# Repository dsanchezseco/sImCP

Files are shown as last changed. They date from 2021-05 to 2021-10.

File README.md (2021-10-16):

# **sImCP**

or *simple ICP* for the friends

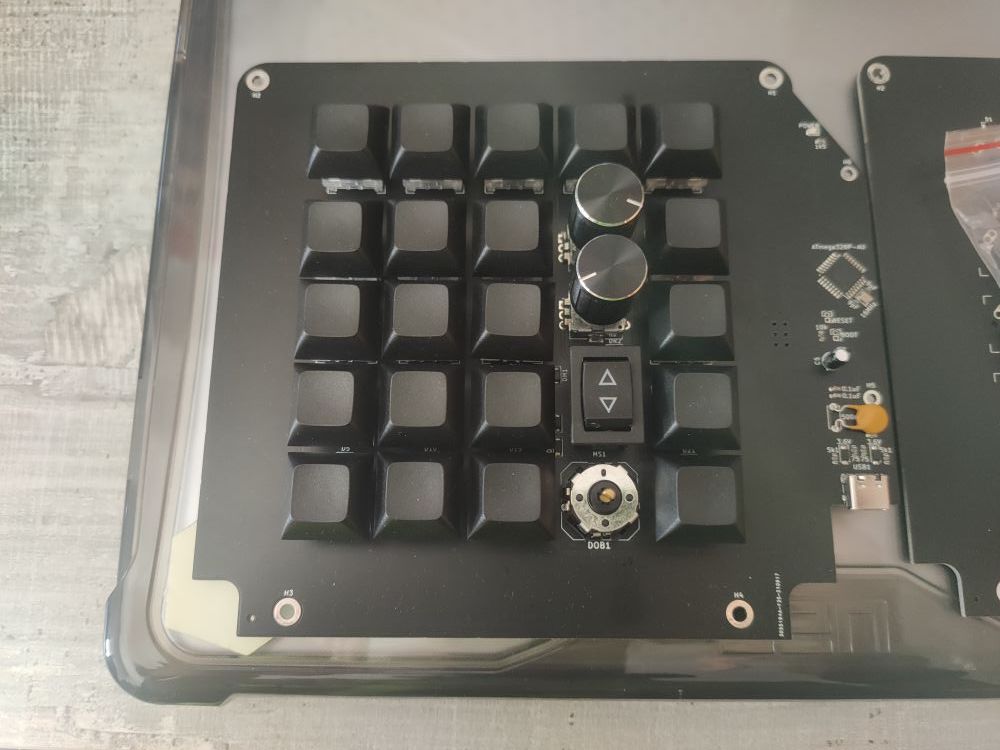
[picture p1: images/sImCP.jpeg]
simcp


sImCP is **custom PCB** powered by an atmega328p to emulate the different aircraft up front controlers (UFC) and input control panels (ICP), mainly a mix of the F-18 and the F-16 panels but with support for others like the AV-8B or the A-10C, for flight simming in DCS an other simulators.

The origin of the project was to have something in the empty space of the MFD in my cockpit, and as such the holes align with the holes and mounting of the Thrustmaster MFDs

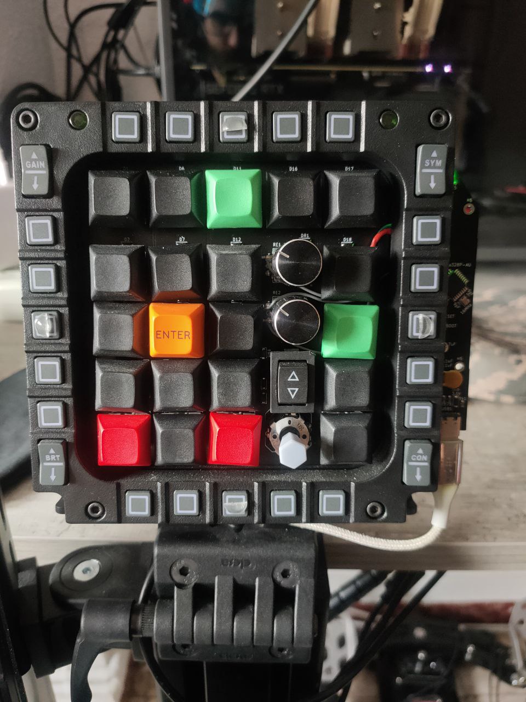
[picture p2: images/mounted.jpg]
mounted


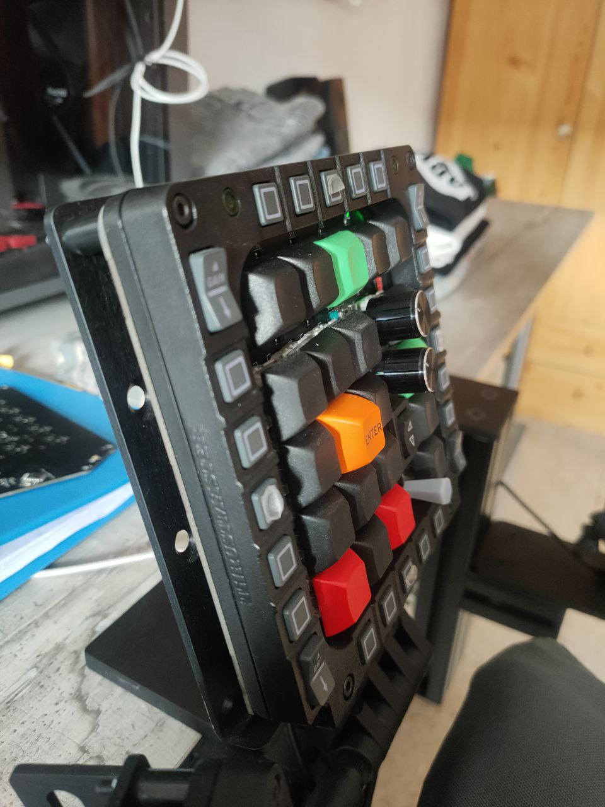
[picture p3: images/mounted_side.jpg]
mounted side


The features that define the **sImCP** are:

* Atmega328p
* USB-C
* 21 keys (MX or ALPS mechanical switches)
* 2 encoders with push
* 1 2-Way switch
* 1 4-Way with push and encoder (called dobber)
* [QMK](https://qmk.fm) support
* Thrustmaster Cougar MFD mountable

In fact it is a **fully programmable keyboard** and as such its keys behaviour can be changed by creating a new custom keymap with QMK and flashing it to the board

### It is a keyboard, so use the keyboard column on DCS to do the keybinds

### **Default keymap**

The default keymap has the following keycodes:

```

   ------------ ----------- ------------- ------------- ------------
   |  LCTL+A  | |  LCTL+O  | |  LCTL+U  | |  LCTL+I   | |  LCTL+D  |
   ------------ ------------ ------------ ------------- ------------
   ------------ ------------ ------------ ------------- ------------
   |  RCTL+1  | |  RCTL+2  | |  RCTL+3  | | ENCODER 1 | |  LCTL+H  |
   ------------ ------------ ------------ ------------- ------------
   ------------ ------------ ------------ ------------- ------------
   |  RCTL+4  | |  RCTL+5  | |  RCTL+6  | | ENCODER 2 | |  LCTL+T  | 
   ------------ ------------ ------------ ------------- ------------
   ------------ ------------ ------------ ------------- ------------
   |  RCTL+7  | |  RCTL+8  | |  RCTL+9  | |  2-WAY    | |  LCTL+N  |
   ------------ ------------ ------------ ------------- ------------
   ------------ ------------ ------------ ------------- ------------
   |  RCTL+]  | |  LCTL+0  | |  RCTL+[  | |  DOBBER   | |  LCTL+;  |
   ------------ ------------ ------------ ------------- ------------

#########################################
   ENCODER 1
#########################################
  RCTL+F   LCTL+Q    RCTL+C
   (         |         )
   v         v         v

#########################################
   ENCODER 2
#########################################
  RCTL+Y   LCTL+J    RCTL+G
   (         |         )
   v         v         v

#########################################
   2-WAY
#########################################
  LCTL+K
    ^
    |

    |
    v
  LCTL+X

#########################################
   DOBBER
#########################################
          LCTL+M                     
            ^                        
            |                       RCTL+B   RCTL+W    RCTL+Z 
LCTL+P <-       -> LCTL+R            (         |         )
            |                        v         v         v
            v
          LCTL+W
```

### **Gamepad**

Instead of being recognised as a keyboard the sImCP can be flashed with a custom made firmware to act as a gamepad and output a button instead a keycode on each of the keys. 

**This feature is currently WIP**

### **Flashing** 

To flash a new keymap refeer to the [FIRMWARE README.md](READY%20TO%20USE%20FILES/FIRMWARE/README.md) under the `READY TO USE FILES` folder. The default keymap file is provided as well in the same folder.

### READY TO USE inventory

* PCB_FABRICATION: what's needed to order more to JLCPCB already in the correct format
* PCB_3DMODEL: in case you want to print something :)
* FIRMWARE: the code to make it running ready to flash
* 3D_PRINTABLES: stuff ready to print like the **dobber cap (by Joghurt - thanks!)**

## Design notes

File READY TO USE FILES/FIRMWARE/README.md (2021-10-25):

These files are the firmware for the sImCP keyboard.

* QMK : regular [QMK](https://github.com/qmk/qmk_firmware) firmware to act as a keyboard. It uses *modifier/s+key* for each of the actions. Can have collisions with default game keybinds but it is recognized in every game/sim that uses a keyboard.

# Flashing - CAUTION!!!

This is a delicate operation. Please follow all the steps and in case of doubt do not procced, **ASK FOR HELP**
## Preparation

1. Grab a piece of wire, tweezers or something conductive to be able to short the `boot` jumper 
2. Download and install [QMK Toolbox](https://github.com/qmk/qmk_toolbox/releases) (can be used with any of the versions)
3. Download the desired `FIRMWARE` from this same folder

## Flashing

1. unplug the board
2. open QMK toolbox
3. click on open and select the downloaded .hex file

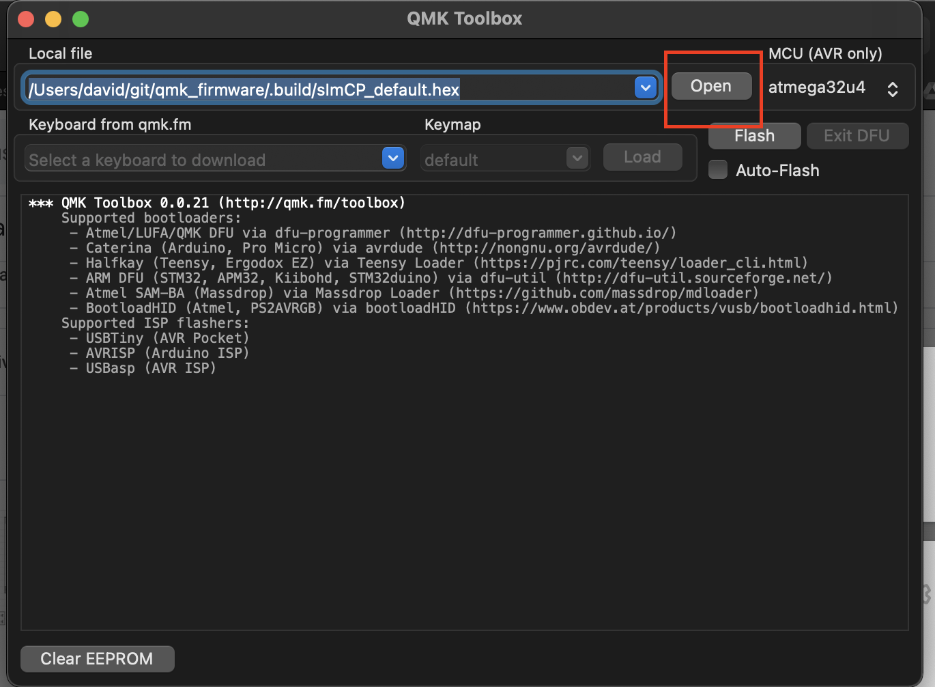
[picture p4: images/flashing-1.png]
select the hex file

￼
4. under MCU select atmega328p

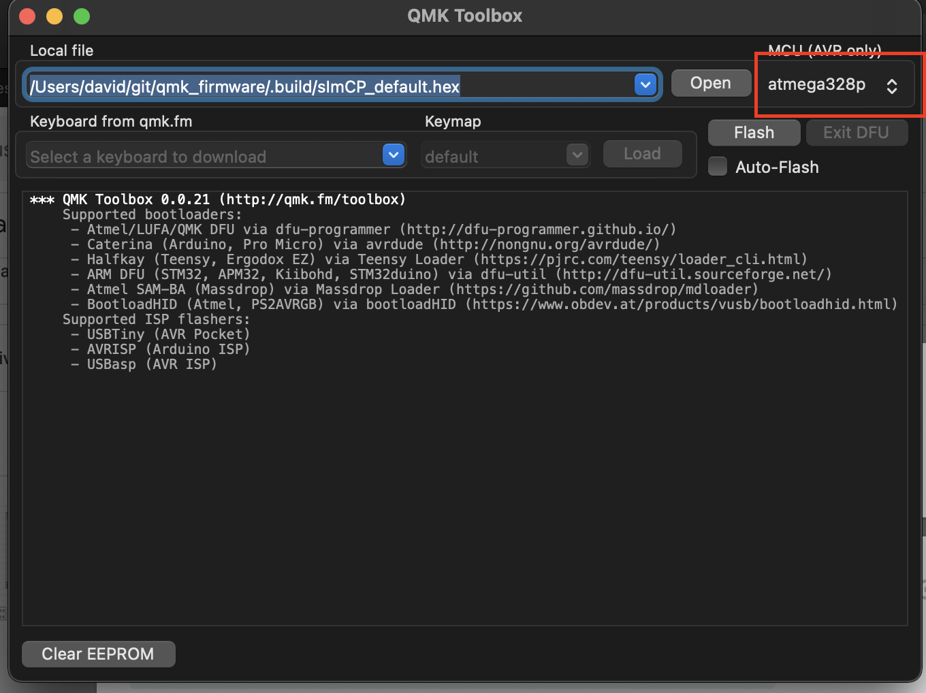
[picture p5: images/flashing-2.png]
select the MCU


5. bridge the BOOT pins with a piece of wire or tweezers

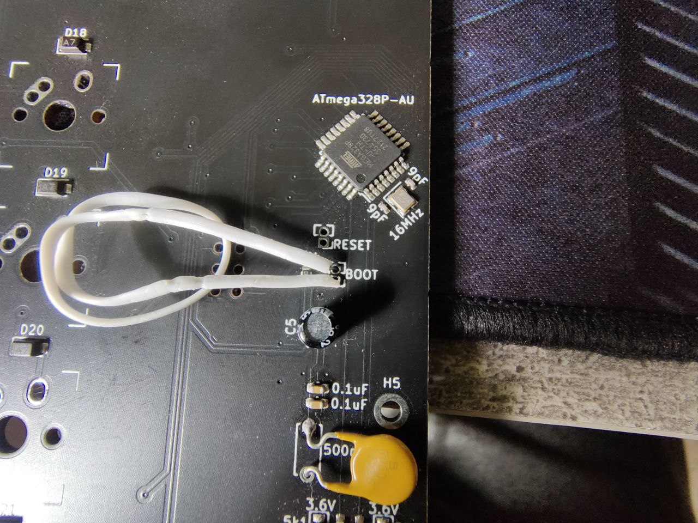
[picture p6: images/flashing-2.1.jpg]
bridge boot


1. Connect the board. The green power light should be off and on the toolbox you should see the yellow line (you can keep the bridge in, if the light goes on, try again, the light has to stay off)
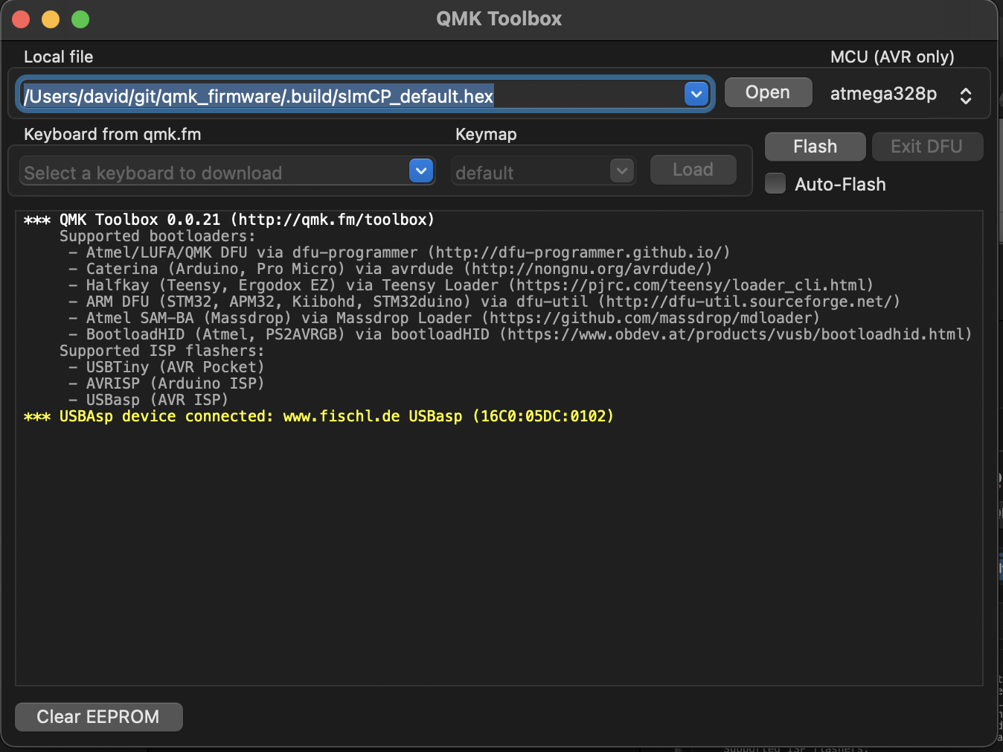
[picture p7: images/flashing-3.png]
MCU recognized


￼

### VERIFY YOU HAVE atmega328p SELECTED!

7. Click on Flash to start the process DO NOT UNPLUG THE BOARD OR CLOSE THE TOOLBOX!

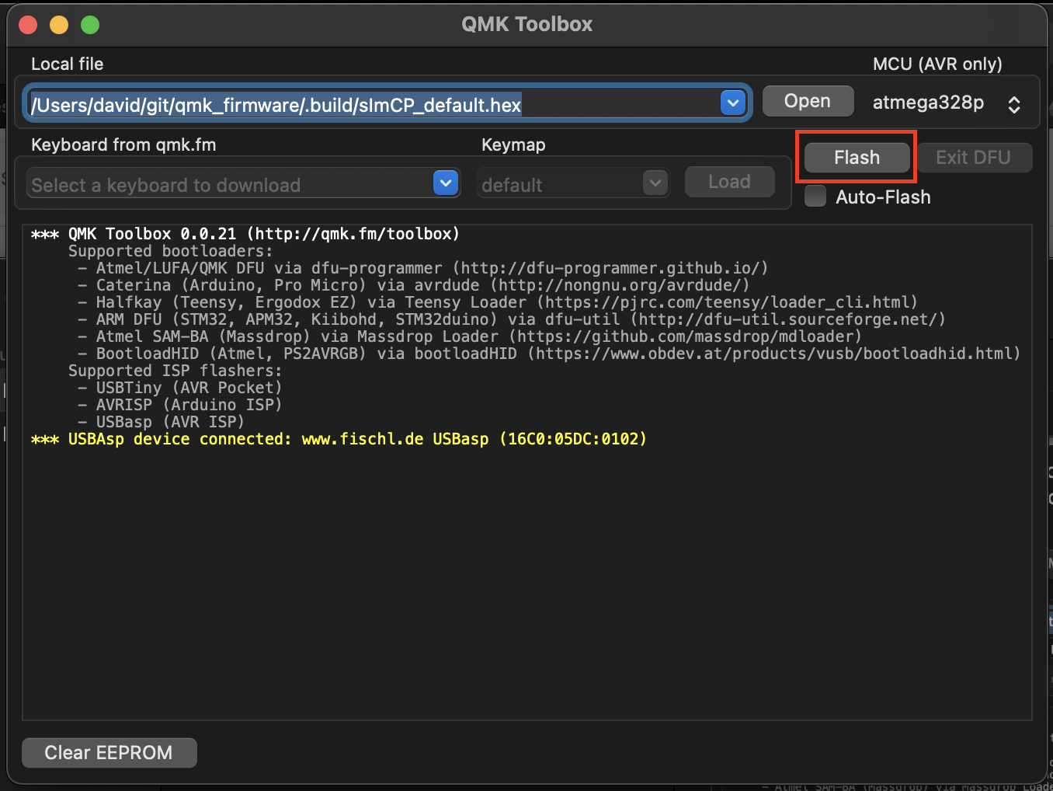
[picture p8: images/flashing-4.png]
flash

￼

When the process is finished you should see
￼
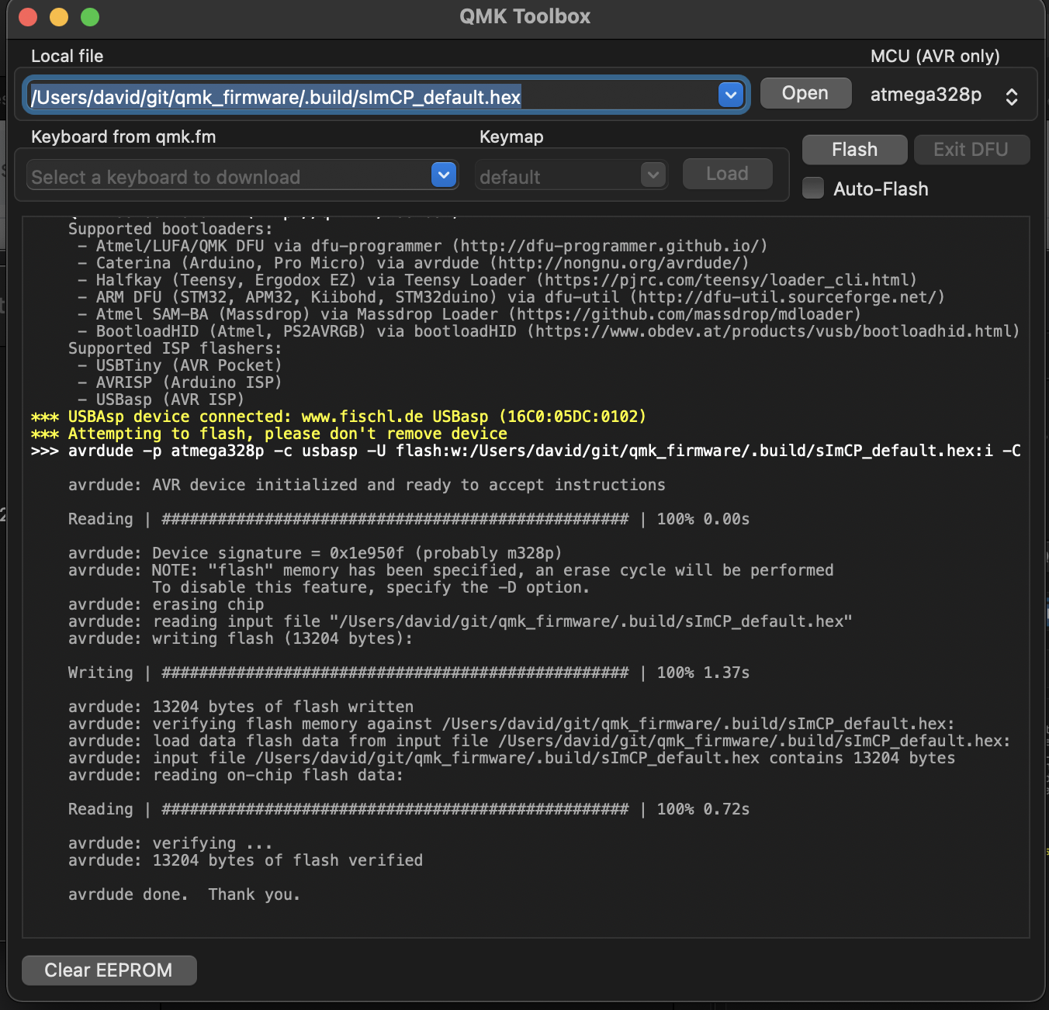
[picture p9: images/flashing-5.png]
done


8. Reconnect the board  or briefly bridge the RESET pins and you are done

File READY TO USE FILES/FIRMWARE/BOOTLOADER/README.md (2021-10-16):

# WARNING!!! You probably don't need these files

This files are to be used with and ISP flasher NOT with regular USB programming.

**If you do not know the terms MCU, ISP, BOOTLOADER or V-USB this is probably not for you.** You have been warned.

## You do not need these files unless the MCU is blank or you sourced the PCBs yourself

The files here are ready to flash a new MCU with both the **bootloader** and the **firmware**. There are two variants:

* QMK : regular [QMK](https://github.com/qmk/qmk_firmware) firmware to act as a keyboard. It uses *modifier/s+key* for each of the actions. Can have collisions with default game keybinds but it is recognized in every game/sim that uses a keyboard.
* Gamepad : custom firmware to act as a gamepad. It is recognized as an standalone device which uses buttons for each action. Do not have collisions with default keybinds but some games/sims may not recognized.

Both versions use (a modified version of ) [USBaspLoader](https://github.com/dsanchezseco/USBaspLoader) to be used with this specific PCB, do not use it with any other.

USBaspLoader provides V-USB (virtual USB) capabilities for not USB ready devices like the **atmega328p** being used here. This way the PCB can use a **low speed USB** controlled via software and **firmware flashing through USB**.

# Flashing - CAUTION!!!

TODO

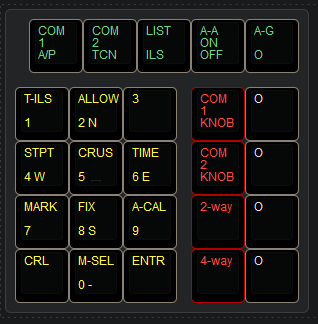
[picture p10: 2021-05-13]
images/sketch.png

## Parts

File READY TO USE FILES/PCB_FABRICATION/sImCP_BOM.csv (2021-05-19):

Comment | Designator | Footprint | LCSC
9pF | C1,C2 | Capacitor_SMD:C_0402_1005Metric | C111805
0.1uF | C3,C4 | Capacitor_SMD:C_0603_1608Metric | C14663
4.7uF | C5 | Capacitor_SMD:CP_Elec_4x5.3 | C134741
D_Small | D1,DR1,DM1,DB1,D2,DR2,DM2,D3,D4,D5,D6,D7,D8,D9,D10,D11,D12,D13,D14,D15,D16,D17,D18,D19,D20,D21 | SOD-123FL:D_SOD-123FL | C426570
RKJXT1F42001 | DOB1 | ALPS_RKJXT1F42001:RKJXT1F42001 | C160841
3.6V | DZ1,DZ2 | Diode_SMD:D_SOD-123 | C82565
500mA | F1 | Capacitor_THT:C_Disc_D5.0mm_W2.5mm_P5.00mm | C208476
MountingHole | H1,H2,H3,H4 | MountingHole:MountingHole_3.2mm_M3_ISO7380_Pad
MountingHole | H5,H6 | MountingHole:MountingHole_2.2mm_M2_DIN965_Pad
AVR-ISP-6 | J1 | random-keyboard-parts:Reset_Pretty-Mask
POWER | LED1 | LED_SMD:LED_0805_2012Metric | C205442
Momentary Rocker Switch | MS1 | RockerSwitch:RockerSwitch
MX-NoLED | MX1,MX2,MX3,MX4,MX5,MX6,MX7,MX8,MX9,MX10,MX11,MX12,MX13,MX14,MX15,MX16,MX17,MX18,MX19,MX20,MX21 | MX_Alps_Hybrid:MX-1U-NoLED | C400228
5k1 | R1,R2 | Resistor_SMD:R_0603_1608Metric | C23186
75 | R3,R4 | Resistor_SMD:R_0603_1608Metric | C4275
1k5 | R5,R7 | Resistor_SMD:R_0603_1608Metric | C22843
10k | R6 | Resistor_SMD:R_0603_1608Metric | C25804
Rotary_Encoder_Switch | RE1,RE2 | Rotary_Encoder:RotaryEncoder_Alps_EC11E-Switch_Vertical_H20mm | C255515
RESET | SW1 | Connector_PinHeader_1.27mm:PinHeader_1x02_P1.27mm_Vertical
BOOT | SW2 | Connector_PinHeader_1.27mm:PinHeader_1x02_P1.27mm_Vertical
ATmega328P-AU | U1 | Package_QFP:TQFP-32_7x7mm_P0.8mm | C14877
USB_C_Receptacle_USB2.0 | USB1 | Connector_USB:USB_C_Receptacle_XKB_U262-16XN-4BVC11 | C393939
16MHz | Y1 | Crystal:Crystal_SMD_2520-4Pin_2.5x2.0mm | C280090

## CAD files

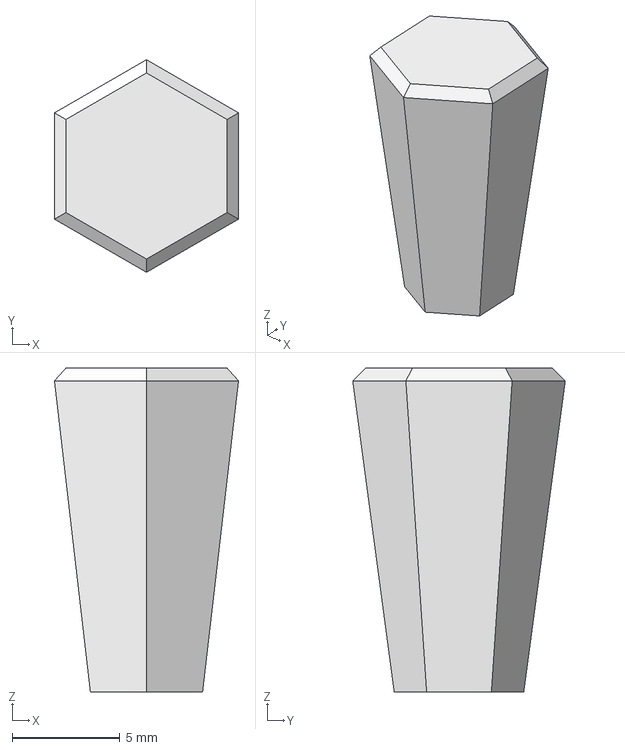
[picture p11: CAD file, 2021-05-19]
READY TO USE FILES/3D_PRINTABLES/MFD_Lever_Cap_6.FCStd
8.52 x 9.84 x 15.0 mm

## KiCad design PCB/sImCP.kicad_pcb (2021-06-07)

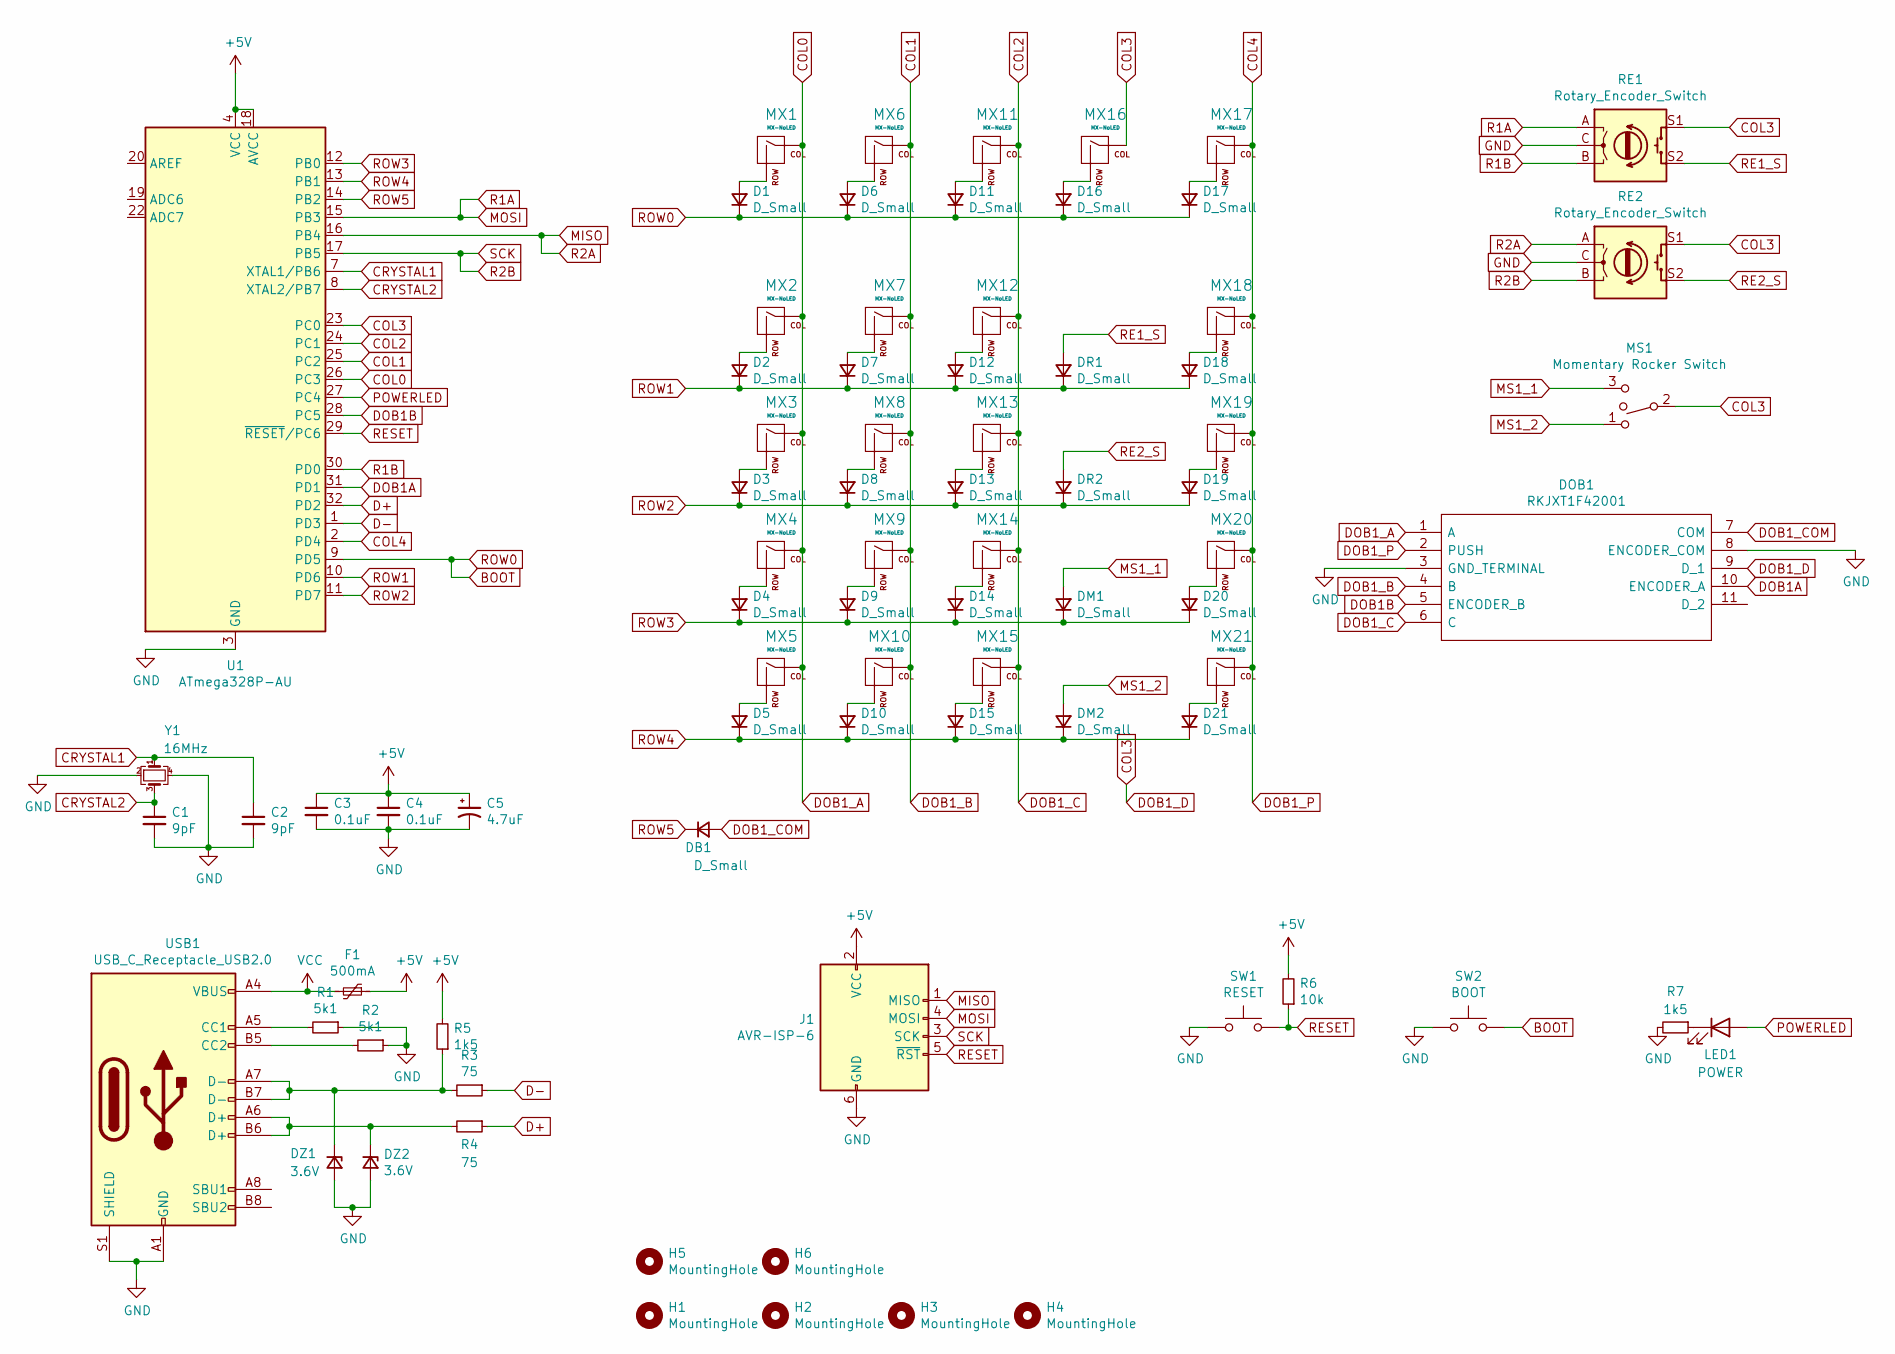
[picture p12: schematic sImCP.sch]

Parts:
C1, C2: 9pF; C_0402_1005Metric; LCSC C111805
C3, C4: 0.1uF; C_0603_1608Metric; LCSC C14663
C5: 4.7uF; CP_Elec_4x5.3; LCSC C134741
D1, D2, D3, D4, D5, D6, D7, D8, D9, D10, D11, D12, D13, D14, D15, D16, D17, D18, D19, D20, D21: D_Small; D_SOD-123FL; LCSC C426570
DB1: D_Small; D_SOD-123FL; LCSC C426570
DM1, DM2: D_Small; D_SOD-123FL; LCSC C426570
DOB1: RKJXT1F42001; Mouser Part Number 688-RKJXT1F42001
DR1, DR2: D_Small; D_SOD-123FL; LCSC C426570
DZ1, DZ2: 3.6V; D_SOD-123; LCSC C82565
F1: 500mA; C_Disc_D5.0mm_W2.5mm_P5.00mm; LCSC C208476
H1, H2, H3, H4: MountingHole; MountingHole_3.2mm_M3_ISO7380_Pad
H5, H6: MountingHole; MountingHole_2.2mm_M2_DIN965_Pad
J1: AVR-ISP-6; Reset_Pretty-Mask
LED1: POWER; LED_0805_2012Metric; LCSC C205442
MS1: Momentary Rocker Switch; RockerSwitch
MX1, MX2, MX3, MX4, MX5, MX6, MX7, MX8, MX9, MX10, MX11, MX12, MX13, MX14, MX15, MX16, MX17, MX18, MX19, MX20, MX21: MX-NoLED; MX-1U-NoLED; LCSC C400228
R1, R2: 5k1; R_0603_1608Metric; LCSC C23186
R3, R4: 75; R_0603_1608Metric; LCSC C4275
R5, R7: 1k5; R_0603_1608Metric; LCSC C22843
R6: 10k; R_0603_1608Metric; LCSC C25804
RE1, RE2: Rotary_Encoder_Switch; RotaryEncoder_Alps_EC11E-Switch_Vertical_H20mm; LCSC C255515
SW1: RESET; PinHeader_1x02_P1.27mm_Vertical
SW2: BOOT; PinHeader_1x02_P1.27mm_Vertical
U1: ATmega328P-AU; TQFP-32_7x7mm_P0.8mm; LCSC C14877
USB1: USB_C_Receptacle_USB2.0; USB_C_Receptacle_XKB_U262-16XN-4BVC11; LCSC C393939
Y1: 16MHz; Crystal_SMD_2520-4Pin_2.5x2.0mm; LCSC C280090

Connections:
+5V: C3.1, C4.1, C5.1, F1.1, J1.2 (VCC), R5.2, R6.2, U1.4 (VCC), U1.6 (VCC), U1.18 (AVCC)
BOOT: D1.1 (K), D6.1 (K), D11.1 (K), D16.1 (K), D17.1 (K), SW2.2, U1.9 (PD5)
COL0: DOB1.1 (A), MX1.1 (COL), MX2.1 (COL), MX3.1 (COL), MX4.1 (COL), MX5.1 (COL), U1.26 (PC3)
COL1: DOB1.4 (B), MX6.1 (COL), MX7.1 (COL), MX8.1 (COL), MX9.1 (COL), MX10.1 (COL), U1.25 (PC2)
COL2: DOB1.6 (C), MX11.1 (COL), MX12.1 (COL), MX13.1 (COL), MX14.1 (COL), MX15.1 (COL), U1.24 (PC1)
COL3: DOB1.9 (D_1), MS1.2, MX16.1 (COL), RE1.S1, RE2.S1, U1.23 (PC0)
COL4: DOB1.2 (PUSH), MX17.1 (COL), MX18.1 (COL), MX19.1 (COL), MX20.1 (COL), MX21.1 (COL), U1.2 (PD4)
CRYSTAL1: C2.1, U1.7 (XTAL1/PB6), Y1.1
CRYSTAL2: C1.1, U1.8 (XTAL2/PB7), Y1.3
D+: R4.1, U1.32 (PD2)
D-: R3.1, U1.1 (PD3)
DOB1A: DOB1.10 (ENCODER_A), U1.31 (PD1)
DOB1B: DOB1.5 (ENCODER_B), U1.28 (PC5)
DOB1_COM: DB1.2 (A), DOB1.7 (COM)
GND: C1.2, C2.2, C3.2, C4.2, C5.2, DOB1.3 (GND_TERMINAL), DOB1.8 (ENCODER_COM), DZ1.2 (A), DZ2.2 (A), J1.6 (GND), R1.1, R2.1, R7.2, RE1.C, RE2.C, SW1.1, SW2.1, U1.3 (GND), U1.5 (GND), U1.21 (GND), USB1.A1 (GND), USB1.A12 (GND), USB1.B1 (GND), USB1.B12 (GND), USB1.S1 (SHIELD), Y1.2, Y1.4
MISO: J1.1 (MISO), RE2.A, U1.16 (PB4)
MOSI: J1.4 (MOSI), RE1.A, U1.15 (PB3)
MS1_1: DM1.2 (A), MS1.3
MS1_2: DM2.2 (A), MS1.1
unnamed: D1.2 (A), MX1.2 (ROW)
unnamed: D2.2 (A), MX2.2 (ROW)
unnamed: D3.2 (A), MX3.2 (ROW)
unnamed: D4.2 (A), MX4.2 (ROW)
unnamed: D5.2 (A), MX5.2 (ROW)
unnamed: D6.2 (A), MX6.2 (ROW)
unnamed: D7.2 (A), MX7.2 (ROW)
unnamed: D8.2 (A), MX8.2 (ROW)
unnamed: D9.2 (A), MX9.2 (ROW)
unnamed: D10.2 (A), MX10.2 (ROW)
unnamed: D11.2 (A), MX11.2 (ROW)
unnamed: D12.2 (A), MX12.2 (ROW)
unnamed: D13.2 (A), MX13.2 (ROW)
unnamed: D14.2 (A), MX14.2 (ROW)
unnamed: D15.2 (A), MX15.2 (ROW)
unnamed: D16.2 (A), MX16.2 (ROW)
unnamed: D17.2 (A), MX17.2 (ROW)
unnamed: D18.2 (A), MX18.2 (ROW)
unnamed: D19.2 (A), MX19.2 (ROW)
unnamed: D20.2 (A), MX20.2 (ROW)
unnamed: D21.2 (A), MX21.2 (ROW)
unnamed: DZ1.1 (K), R3.2, R5.1, USB1.A7 (D-), USB1.B7 (D-)
unnamed: DZ2.1 (K), R4.2, USB1.A6 (D+), USB1.B6 (D+)
unnamed: LED1.1 (K), R7.1
unnamed: R1.2, USB1.A5 (CC1)
unnamed: R2.2, USB1.B5 (CC2)
POWERLED: LED1.2 (A), U1.27 (PC4)
R1B: RE1.B, U1.30 (PD0)
R2B: J1.3 (SCK), RE2.B, U1.17 (PB5)
RE1_S: DR1.2 (A), RE1.S2
RE2_S: DR2.2 (A), RE2.S2
RESET: J1.5 (~RST), R6.1, SW1.2, U1.29 (~RESET~/PC6)
ROW1: D2.1 (K), D7.1 (K), D12.1 (K), D18.1 (K), DR1.1 (K), U1.10 (PD6)
ROW2: D3.1 (K), D8.1 (K), D13.1 (K), D19.1 (K), DR2.1 (K), U1.11 (PD7)
ROW3: D4.1 (K), D9.1 (K), D14.1 (K), D20.1 (K), DM1.1 (K), U1.12 (PB0)
ROW4: D5.1 (K), D10.1 (K), D15.1 (K), D21.1 (K), DM2.1 (K), U1.13 (PB1)
ROW5: DB1.1 (K), U1.14 (PB2)
VCC: F1.2, USB1.A4 (VBUS), USB1.A9 (VBUS), USB1.B4 (VBUS), USB1.B9 (VBUS)

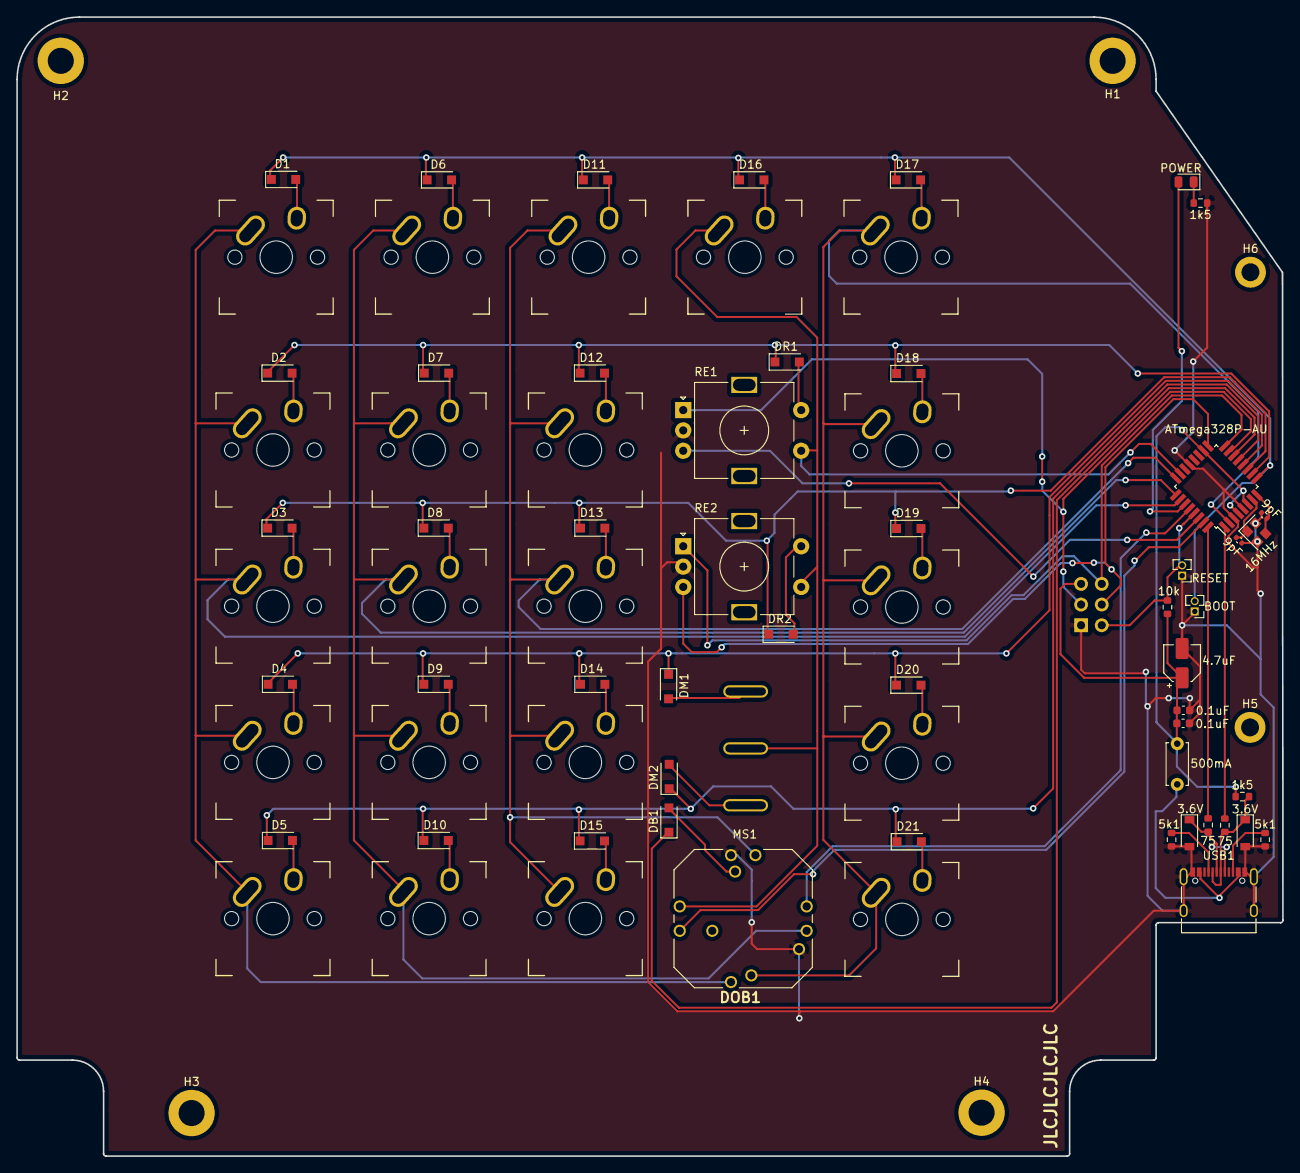
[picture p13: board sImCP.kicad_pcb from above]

Board: 2 copper layers, 155.6 x 140.0 mm, 79 parts (1 on the bottom side), 57 nets.

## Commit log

2021-05-13 Proyect start
    [FF2.kicad_pcb, FF2.sch]
2021-05-13 Started electrical diagram
    Added switches and random keyboard parts libs
    Added sketch of components placement
    [FF2.sch]
2021-05-13 added extra row for the 5-way
    [FF2.sch]
2021-05-14 added rest of the components
    using atmega328p with an USB-C and SMD components
    Dobber is missing
    [FF2.sch]
2021-05-15 Added dobber symbol and footprint and wiring
    added footprint for missing components, missing rocker switch
    [FF2.sch]
2021-05-15 added more footprint associations
    [FF2.sch]
2021-05-15 Start of pcb components placement
    [FF2.kicad_pcb, PCB_shape.dxf]
2021-05-15 updated switches footprints lib, start of placement on board
    [FF2.kicad_pcb, FF2.sch, PCB_components_placement.dxf]
2021-05-15 more component placement on the pcb
    [FF2.kicad_pcb]
2021-05-16 trace routing
    [FF2.sch]
2021-05-16 more routing, only dobber and 2-way missing
    [FF2.kicad_pcb, FF2.sch]
2021-05-17 updated with all SMD on the front and part numbers for production
    [FF2.kicad_pcb, FF2.sch]
2021-05-17 updated silk values to be printed
    [FF2.kicad_pcb]
2021-05-17 updated footprint for boot and reset headers
    [FF2.kicad_pcb, FF2.sch]
2021-05-18 added dobber's encoder connection to MCU
    [FF2.sch]
2021-05-18 routed dobber and renamed files to sImCP
    [FF2.kicad_pcb, FF2.sch, sImCP.kicad_pcb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]
2021-05-18 moved all to root
    [sImCP.kicad_pcb, sImCP.sch]
2021-05-18 added rocker switch footprint
    [sImCP.kicad_pcb, sImCP.sch]
2021-05-18 added new 3dmodels
    [sImCP.kicad_pcb, sImCP.sch]
2021-05-18 added some artwork
    [sImCP.kicad_pcb]
2021-05-18 special parts spaced out
    [sImCP.kicad_pcb]
2021-05-18 added rocker switch 3dmodel
    [sImCP.kicad_pcb]
2021-05-18 added keycaps to switches
    [sImCP.kicad_pcb]
2021-05-18 added encoder knob 3d model
    [sImCP.kicad_pcb]
2021-05-19 update diode footprint to SOD-123FL
    [sImCP.kicad_pcb, sImCP.sch]
2021-05-19 changed USB-C 3dmodel
    [sImCP.kicad_pcb]
2021-05-19 update rocker switch 3dmodel
    [sImCP.kicad_pcb]
2021-05-19 added dobber cap made by Joghurt - thanks!!
    [sImCP.kicad_pcb]
2021-05-19 changed wiring to encoders sharing pins
    [sImCP.sch]
2021-05-19 repo reorg
    [PCB_components_placement.dxf, PCB_shape.dxf, sImCP.kicad_pcb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]
2021-05-19 added BOM
    [sImCP_BOM.csv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]
2021-05-19 Dobber cap printable by Joghurt
    [MFD_Lever_Cap_6.FCStd]
2021-05-19 rerouted with new encoder wiring
    [sImCP.kicad_pcb, sImCP.sch]
2021-05-19 fabrication files for pcb
    [sImCP.kicad_pcb, sImCP_BOM.csv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]
2021-05-31 fixed encoders mess, wiring missing
    [sImCP.kicad_pcb, sImCP.sch]
2021-06-07 updated pcb with new routing for the encoders
    now using a set of pins for each encoder instead of the shared model
    [sImCP.kicad_pcb]
2021-06-09 updated step file for 3d model of pcb
